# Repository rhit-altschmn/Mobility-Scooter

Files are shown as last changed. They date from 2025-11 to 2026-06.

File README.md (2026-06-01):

# Mobility-Scooter
This is a repo to handle code for automating a mobility scooter. A joint partnership between Intro to Robotics team and Dr. Bill Smart's lab. For this project, we added cameras and sensors to the scooter frame, designed a steering system to drive the scooter from afar, and hacked into the scooter's electrical system to power our new electronics. For more information about each of these systems please click the associated link. [Camera System](Cameras.md), [Sensors](Sensors.md), [Steering](SteeringSystem.md), [Electrical System](driveANDelectrical.md)  The scooter is teleoperated throuh a flask server hosted on the onboard Raspberry Pi. An external device can connect to the flask server by being on the same wifi network as the pi and entering the Pi IP address into the search bar. 

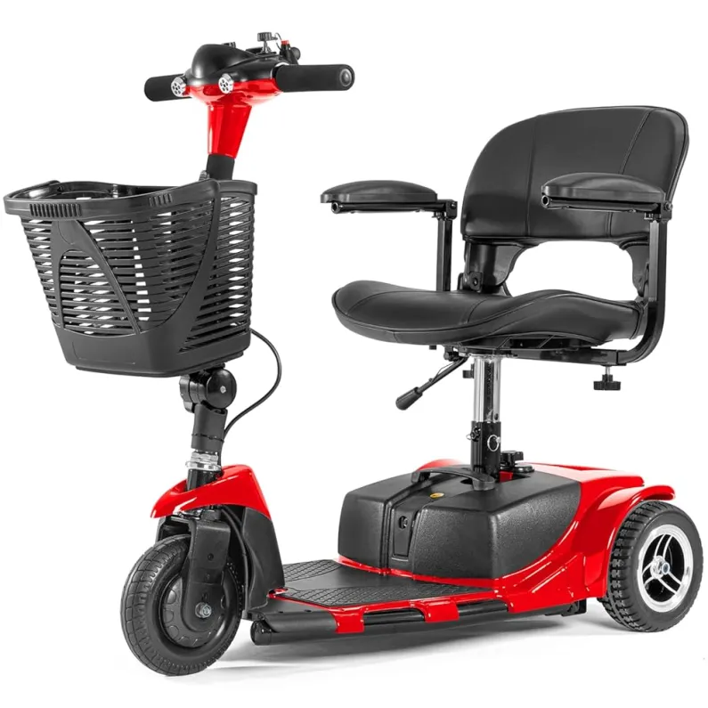
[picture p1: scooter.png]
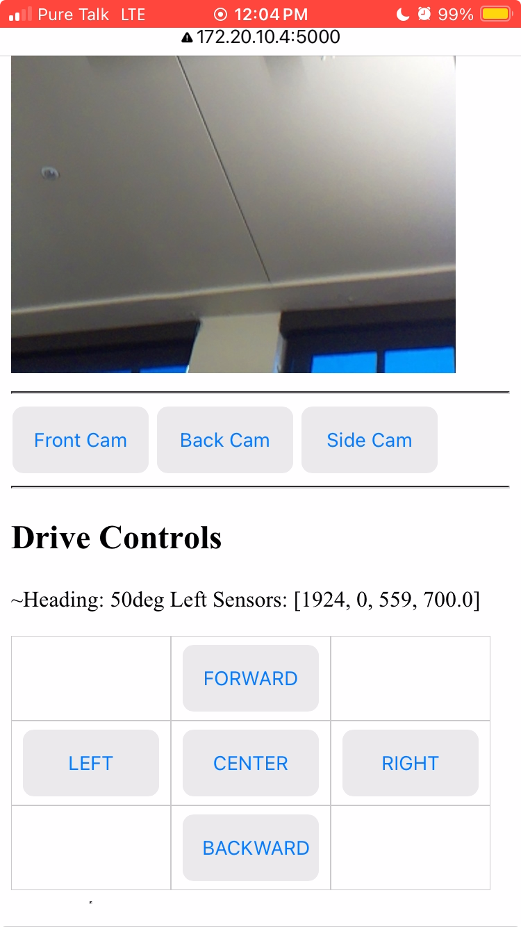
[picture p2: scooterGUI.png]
   &emsp; &emsp; &emsp; &emsp;     <br>
 &emsp; &emsp; &emsp; &emsp;  The Scooter   &emsp; &emsp; &emsp; &emsp; &emsp; &emsp; &emsp; &emsp;       Scooter Graphical User Interface 

<!--Quick guide to markdown (https://www.markdownguide.org/basic-syntax/#links)-->

## Hardware
* Raspberry Pi4 - the brain that runs code and hosts the flask server
* Stepper Motor - used with belt system on drive shaft for steering front wheel
* Voltage-stepdowns - used with PWM for controlling rear wheels powerin the scooter forward/backward
* Cameras (2 USB and 1 picam) - for viewing so users can teleop the scooter. maybe used for computer vision in future
* ultrasonics (4) - for object avoidance sensing

### Raspberry Pi info
Raspberry Pi login stuff:
username: scooterteam

password: scooter1

local LAN ssid: scooterwifi

password:scooter1

## Software
* scooterSite.py - runs the flask site html and handles camera frame creation and streaming to site
* templates/index.html - the html for the flask site
* static/main.js - the javascript to handle button pushes on the html
* scooterController.py - does all the backend scooter control:
  - initializes all the GPIO pins and serial ports
  - calls the appropriate functions for moving & turning scooter
  - handles ultrasonics gets readings and publishes them.
* motor_driver.py - calculates the correct pwm setting for desired turn angle

  all the other files are old testing files not needed in final scooter operation.

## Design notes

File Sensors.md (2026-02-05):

# Ultrasonic Distance Sensors

## Overview
Four [A02YYUW waterproof ultrasonic distances](https://www.dfrobot.com/product-1935.html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) were put on the scooter. One was placed to view each direction, with the left and right sensors being mounted low and pointed slightly upwards in an effort to see cars nearby in a parking lot scenario. The rear sensor uses a [3D printed mount](https://cad.onshape.com/documents/c4d6c58f98211453321110ab/w/8268dd0c223b57df2334ac4d/e/cfee72e95296e9f6bdb92858) inserted into the hitch. This file is also given as Ultrasonic and Camera Rear Mount in the Github. These distance readings are used for safe navigation, ensuring that a user or autonmous controller are aware of any obstacles.

## Setup
The A02YYUW operates at either 3.3 or 5V, and will output the same voltage. If using with a Raspberry Pi it is important to power with 3.3V to avoid damaging any pins. Please see the [datasheet](https://media.digikey.com/pdf/Data%20Sheets/DFRobot%20PDFs/SEN0311_Web.pdf) for relevant information.

Note that the blue wire is TX and Green is RX for UART.

Setup procedure on a new Pi is as follows:
1. Enable UART in config by using `sudo nano /boot/config.txt` and adding the following to the bottom:
   `dtoverlay=disable-bt  
   enable_uart=1  
   dtoverlay=uart3  
   dtoverlay=uart4  
   dtoverlay=uart5`  
2. Disable bluetooth with the following:
   `sudo systemctl disable hciuart.service  
   sudo systemctl mask hciuart.service  
   sudo reboot`  
3. Install pyserial with:
   `pip install pyserial`

## Code
Please see ultrasonic.py for example code on using the sensors. If the serial ports are not working you can verify the ports with `ls /dev/ttyAMA`. The CPU speed function is useful for checking the load cuased by the sensors, with speeds below 1100 being ideal for continouse use without cooling. For a Raspberry Pi 4B the wiring must be done as follows:
	Sensor 1: Blue(TX) to GPIO14, Green(RX) to GPIO15
	Sensor 2: TX to GPIO4, RX to GPIO5
	Sensor 3: TX to GPIO8, RX to GPIO9
	Sensor 4: TX to GPIO12, RX to GPIO13
The final intent for the sensors is to read distance and limit movement such that you cannot move closer to an object once a certain threshold is met. This is not yet implemented into the controls code.

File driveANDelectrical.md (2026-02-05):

## Drive System / Electrical Documentation

## Overview

The drives interface takes over from the user-operated paddle switch for vehicle control. In order to preserve user operation modes, the drive system switches it's command inputs between the human and the electronic interface.

## Electrical Infrastructure

The auxiliary electrical infrastructure of the vehicle is provided by a single voltage stepdown module. This module takes the 12V nominal bus of the scooter, tapped from the ignition/key circuit, and provides 5V power to the steering servomotor, Raspberry Pi, both drive DACs, and the drive relays.

Using a monitored/digital step-down in this role enabled amperage monitoring, and power draw estimations. In further exploration of this technology, this implementation or similar would be advised. Technically, at 5V, the steering motor is under-volted, but undervolting in this case was found to not have significant performance degradation.

## Drive Interface

The drive interface primarily consists of two ADCs, and two relays.

The relays, in their nominally closed position, allow passthrough or "connection" of the drive signal from the thumb-throttle potentiometer. When opened, the relays connect to driven outputs of the digital-to-analog converters, and send voltage outputs along those rails.

The potentiometer used by the driver is a wiper-style, with a single input, and two outputs. At zero command, both outputs are driven to about 2.5V. When given an input, one output is pulled high, and the other is driven low. In function, the DACs follow this same logic, one pulls higher, the other pulls lower. 

In addition, the motor controller has several safety features that make this problematic. Primarily, the controller monitors for voltage discontinuities, and input coherence. As such, changeover/switchover events from the manual control to the automatic control must occur at zero throttle command. To the controller, the 2.5V from the potentiometer must seamlessly become the 2.5V from the DACs, or a fault will trigger. This same rule applies in the reverse transition state, switching from automated to manual control requires the output to be zeroed. Additionally, the inputs to the controller are monitored in the time domain, so large instantaneous jumps in throttle from the DAC have the potential to trigger fault modes.

Fault modes (characterized by a generic 7-beep sequence) cannot be reset without a vehicle restart, and should be avoided at all costs. 

Proper sequencing of a drive input for movement is as follows:
1. User throttle at zero
2. DACs are spun-up to 2.5v or "zero" command, and a delay is recommended here
3. Relays are engaged, switching control to digital system
4. DACs are incrementally stepped up to drive command voltage (one goes up, other goes down)
5. Drive command voltage is sustained for the length of the movement
6. DACs are incrementally stepped down to zero
7. Relays are disenaged, returning control to user

Following this cycle will result in minimal fault engagements upon motion.

## Pitfalls / Known Issues

Common issues discovered with this implementation can be found below:

* Large throttle commands can trigger fault modes, typically above 25% forward throttle command. This is theorized to be a result of the usage of two individually-driven digital-to-analog converters. As commanded throttle increases, the noise floor between the two DAC outputs increases, suspected to trigger the fault condition in the controller. This is exascerbated by sustained operation of the throttle.
* Failure to increment/slowly build commanded throttle can trigger fault modes, due to discontinuity checks within the controller.
* The potentiometer is never fully removed from the circuit, and as such may have an unmodeled role in the fault triggering mechanics.
* Improper sequencing in control logic can trigger faults. Similarly, improper timing of input sequencing can have the same effect

## Current State / Reccomendations

Currently, the drive controller is capable of converting impulse (one off) movement inputs into incremental movements for short durations of time. This model was chosen over a sustained movement option for simplicity on the web-controller side. A sustained motion model is certainly more desireable, but as discussed above, the input system is sequence-dependent, and that was difficult to implement during the time allowed. The code to execute this can be found in scooterController.py

For future implementations, a twin-DAC solution should be moved away from, with instead the use of a 5V inverting op-amp providing direct inversion of one signal, without noise floor effects.

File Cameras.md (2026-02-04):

# Camera System Documentation

## Overview

During teleoperation of the mobility scooter, there is a high likelihood that the scooter may move out of the operator’s direct line of sight. To address this challenge, the team developed a three view camera system to provide continuous visual feedback of the scooter’s surroundings.

This system enables real time monitoring by providing views from the front, rear, and left side of the scooter. The left side view is particularly useful during docking operations. Together, these views improve situational awareness and enhance safe remote operation.

---

## Camera System

The camera system consists of one PiCamera and two USB cameras.

The PiCamera is mounted at the front of the scooter to provide the forward facing view.  
One USB camera is mounted at the rear to provide the back view.  
Another USB camera is mounted on the left side to assist during docking.

The PiCamera is connected directly to the Raspberry Pi 4B through the dedicated camera interface port. The two USB cameras are connected through USB extension cables to the available USB ports on the Raspberry Pi.

For demonstration purposes, non waterproof cameras were selected to reduce cost. However, these cameras can be enclosed in waterproof housings for outdoor or adverse weather use.

## Specifications
-  PiCamera            - https://www.raspberrypi.com/documentation/accessories/camera.html#camera-module-2
-  USB Camera(FIT0892) - https://www.digikey.com/en/products/detail/dfrobot/FIT0892/18069226

---

## Integration into the General System

The camera system is integrated into the local domain host using a Flask based web interface.

A single display window is designed to showcase the selected camera view. Three control buttons are provided to allow the operator to switch between camera feeds in real time:

- FRONT CAM for the front view  
- BACK CAM for the rear view  
- SIDE CAM for the left side view  

These controls enable flexible and efficient monitoring during teleoperation.

---

## Current State of the Camera System

Currently, the camera system is not fully operational due to power limitations of the Raspberry Pi when supporting all cameras and other system components simultaneously.

- The rear and side cameras are physically disconnected and unmounted from their designated positions  
- The PiCamera remains mounted but is currently disconnected  
- All other system components remain as described in the previous sections  

These limitations are temporary and will be addressed through future power management and hardware upgrades.

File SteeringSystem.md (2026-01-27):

## Steering System

### Overview
In order to drive automously we need to remotely steer the mobility system. The base mobility sccooter has no powered steering and is manually steered through turning the handle bars which turn a steering column. Therefore, the steering system needs to mount on the frame of the mobility scooter and allow powered steering.

### Goals
* Allow the pi to autonomously control the angle of the steering column when powered on
  * This assumes that there is no rider or additional weight on the scooter while being autonomously operated. 
* Allow the scooter rider to manually steer the scooter while riding it
  * This will require either  a clutch or backdriving the motor. For the sake of simplicity, we chose to backdrive the motor.
* Attach to the frame of the scooter with minimal damage or modifications
* Allow precise control of the angle of the front wheel.
  * For the sake of simplicity, this version is open loop control. 

### Design
The steering angle is controlled by driving a servo mounted the the frame and belted to the steering column. The 2:1 gear ratio combined with the manual leverage from the handle bars make it reasonable to backdrive the unpowered servo without much difficulty. The motor requires a stepdown in voltage from the system power and is connected to the voltage stepdown in the central control box. This resulted in the motor being slightly undervolted at 5V instead of 6V. During tests, the motor was slower, but no less accurate. The belt sprockets used are 3D printed based on McMaster-Carr sprockets. The largest sprocket is left unchanged. The smaller sprocket has a large hole bored through the middle to accomodate the steering column and a small hole perpendicular to that to accomodate the bolt on the steering column. To reduce skipping, it is important that the mount is as rigid as possible. There is a shim used in the clamp to help tension the belt appropriately. To control the servo, you can use the "motor_driver.py" file. This file contains a function that takes the desired angle and Hz as an input. Then, it can either return the needed duty cycle for the pwm, or it can directly set the pwm. The gear ratio can also be modified in the function. 

front

### Parts
* Annimos servo motor: https://www.amazon.com/dp/B0C69WWLWQ
* DROK DC Buck Converter: https://www.amazon.com/DROK-Converter-5-3V-32V-Regulator-Transformer/dp/B078Q1624B
* 1.75in OD Pulley: https://www.mcmaster.com/1277N23
* 3.28in OD Pulley: https://www.mcmaster.com/57105K32
* 13in Timing belt: https://www.mcmaster.com/1679K121
* 3D printed parts as shown in the CAD

### Installation
1. Print out both belt sprockets, both halves of the clamp, and the shim from the CAD.
2. Remove the two bolts on the steering column and split it into two pieces. Slide the smaller belt sproket and the belt on the steering column. Reattach the steering column.
3. Screw the round aluminum servo horn on to the large belt sprocket. Install sprocket on the servo.
4. Bolt the servo bracket to the clamp with a shim in between. The width of the shim can be adjusted to adjsut the tension in the belt. You may need to drill out the 3D printed holes. Screw the bracket into the servo motor. 
5. Align the clamp around the frame of the scooter. You may need to add a strip of double sided tape or foam to adjsut fit. Secure the belt around both sprockets. Bolt the two halves of the clamp together, starting with the bolt on the bottom.
6. Regularly inspect the mount for cracks or fatigue.
   
### Documentation
https://cad.onshape.com/documents?nodeId=2ab928cb0acfaec854c34554&resourceType=folder

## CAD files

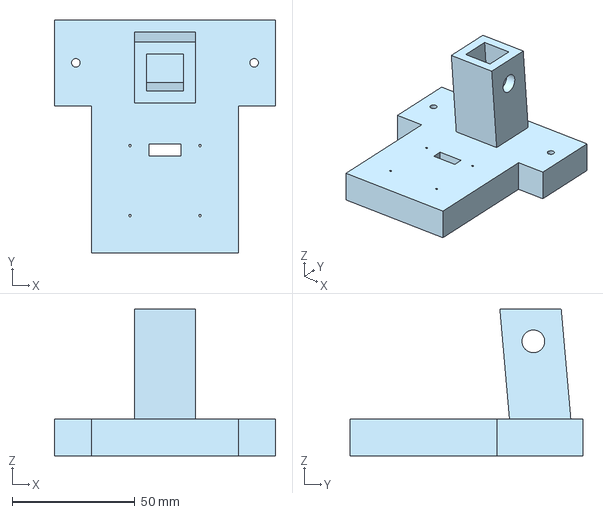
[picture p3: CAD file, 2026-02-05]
CADfiles/Ultrasonic and Camera Rear Mount.step
90.0 x 95.0 x 59.8 mm

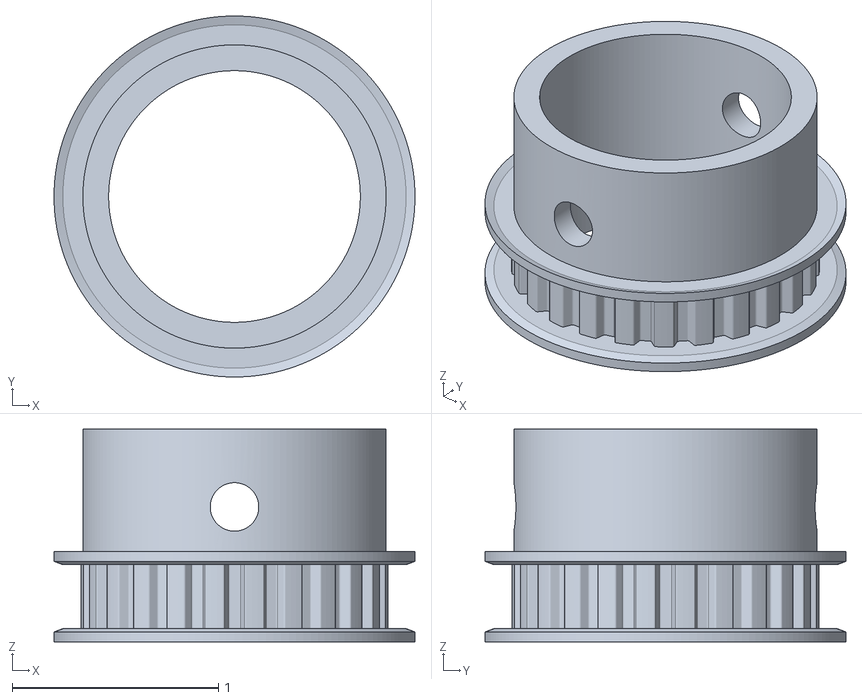
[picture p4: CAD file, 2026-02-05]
CADfiles/Small Belt Sprocket.stl
1.75 x 1.75 x 1.03

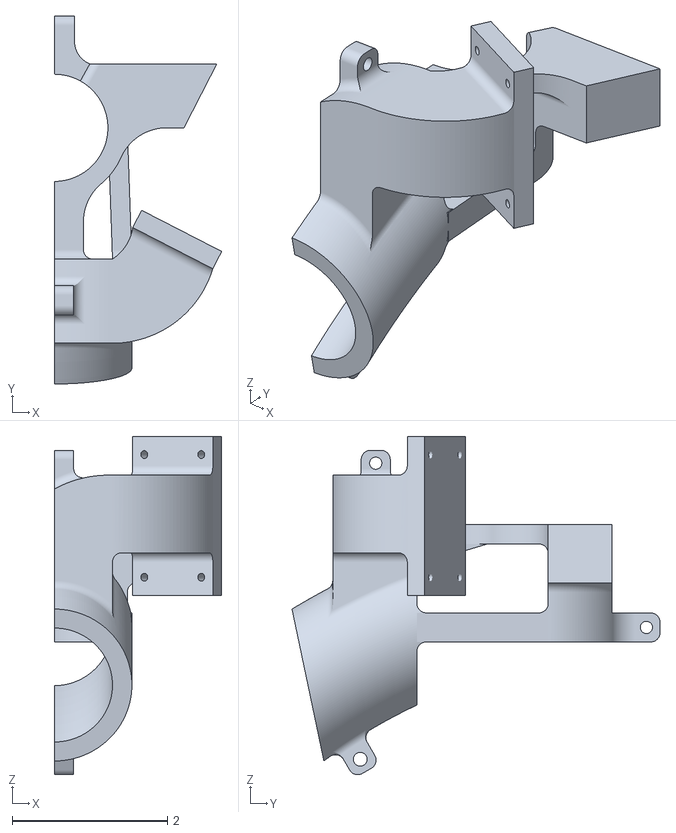
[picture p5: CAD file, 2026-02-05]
CADfiles/Actuator Clamp - Part 1.stl
2.16 x 4.74 x 4.36

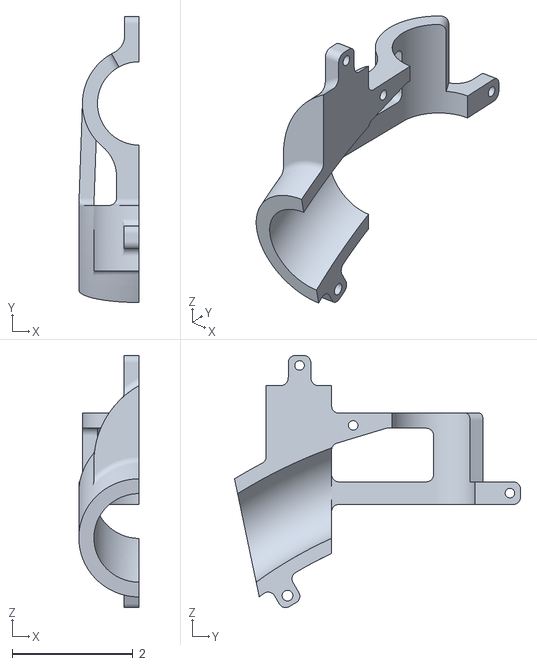
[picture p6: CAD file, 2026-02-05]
CADfiles/Actuator Clamp - Part 2.stl
1 x 4.74 x 4.18

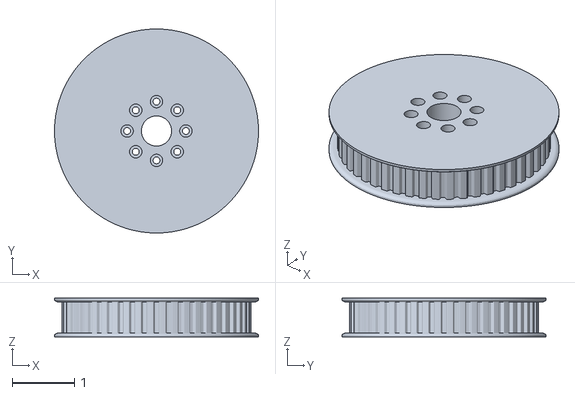
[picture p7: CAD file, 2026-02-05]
CADfiles/Large Belt Sprocket.stl
3.28 x 3.28 x 0.625

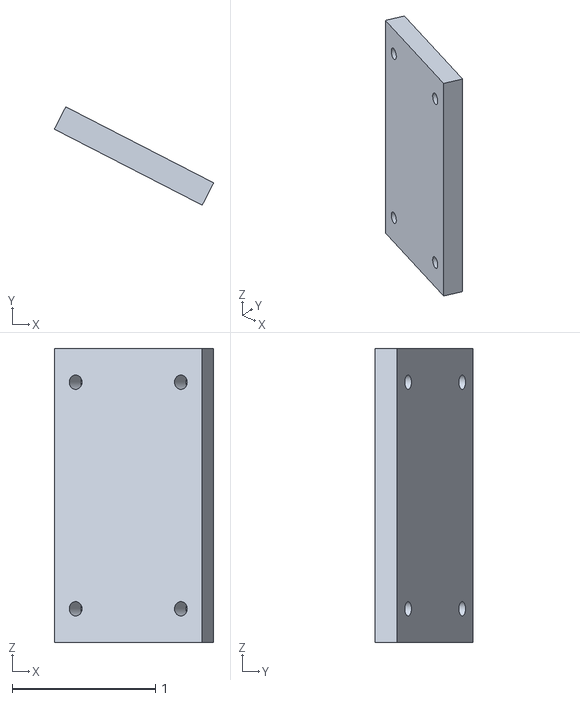
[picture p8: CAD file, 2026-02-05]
CADfiles/Actuator Clamp - Shim.stl
1.11 x 0.686 x 2.05

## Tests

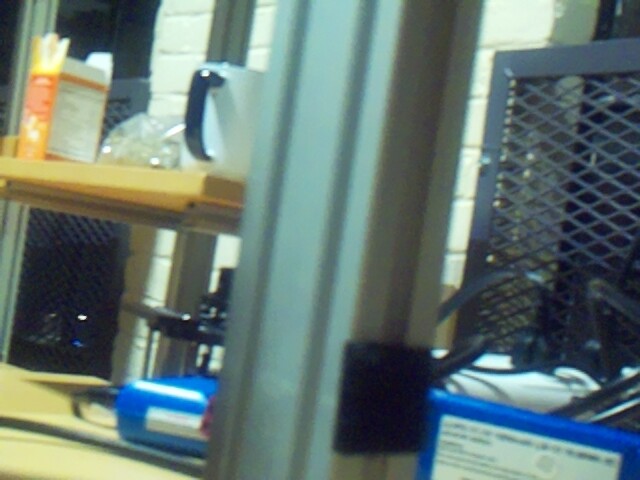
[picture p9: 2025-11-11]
testing_code/test.jpg

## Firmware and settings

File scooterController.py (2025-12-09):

import RPi.GPIO as GPIO
from time import sleep

import motor_driver
GPIO.setmode(GPIO.BOARD)

import serial
#import ultrasonic just copied functions
import random


class scooterController:

    def __init__(self):
        #pwm.stop()
        GPIO.setup(40,GPIO.OUT) # DAC1 pwm
        GPIO.setup(38,GPIO.OUT) # relay 1 hi/lo
        GPIO.setup(37,GPIO.OUT) # DAC2 pwm
        GPIO.setup(35,GPIO.OUT) # relay 2 hi/lo
        GPIO.setup(11,GPIO.OUT) #change this pin as needed
        
        self.Hz = 250
        
               
        self.pwm = GPIO.PWM(11,self.Hz) #MOTOR HZ CAN BE 50-330
        self.pwm1 = GPIO.PWM(40,1000) #set duty cycle to 50Hz or 20 ms
        self.pwm2 = GPIO.PWM(37,1000) #set duty cycle to 50Hz or 20 ms
        #operating frequency is 50-330Hz

        #motor operates from 500-2500 microseconds or 0.5-2.5ms
        #motor nuetral is at 1500 microseconds or 1.5ms

        #set motor to neutral
        self.heading = 0
        cycle = motor_driver.turn_to_angle(self.heading,self.Hz)
        self.pwm.start(cycle) #sets to center
        
        sleep(1)
        print("resetting header")

        # Assigned Pins:
        # S1: Blue(TX) to GPIO14, Green(RX) to GPIO15
        # S2: TX to GPIO4, RX to GPIO5
        # S3: TX to GPIO8, RX to GPIO9
        # S4: TX to GPIO12, RX to GPIO13
        # Setting serial ports for each sensors, skip AMA1 and 2
        self.ports=[
                serial.Serial("/dev/ttyAMA0",9600,timeout=0.1),
                #serial.Serial("/dev/ttyAMA3",9600,timeout=0.1),
                serial.Serial("/dev/ttyAMA4",9600,timeout=0.1),
                serial.Serial("/dev/ttyAMA5",9600,timeout=0.1)
        ]
        # Flushing ports and waiting for sensors to stabilize
        print("Resetting serial ports")
        for ser in self.ports:
            ser.reset_input_buffer()
        sleep(1.0)

        self.distances = []
        
    def read_dist(self,ser):
        data=ser.read(4)
        distance = (data[1] * 256 + data[2])
        #print(f"single dist read: {distance}")
        return distance
        
    def distance_read(self):
        self.distances = []        
        for ser in self.ports: # Add each distance reading
                ser.reset_input_buffer()
                dist = self.read_dist(ser)
                #if self.distances != None:
                self.distances.append(dist)
        with open("/sys/devices/system/cpu/cpu0/cpufreq/scaling_cur_freq") as cpu:
                Speed = int(cpu.read().strip()) / 1000 # Convert to mHz
                self.distances.append(Speed)
        #print(f"dist read: {self.distances}")

    def controlCommand(self,command):
        print(f"Controller Read: {command}")
        
        self.distance_read()
        print(f"Controller Distances: {self.distances}")
        #self.distances.append(random.randint(0,9)) # For sensor 4, not attached yet
        
        match command:

            case "RIGHT":
                self.heading = self.heading -10
                if self.heading < -70:
                    self.heading = -70
                cycle = motor_driver.turn_to_angle(self.heading,self.Hz)
                self.pwm.ChangeDutyCycle(cycle)
                print(f"Right: {self.heading}  {cycle}")
                
            case "CENTER":
                self.heading = self.heading * 0.75
                cycle = motor_driver.turn_to_angle(self.heading,self.Hz)
                self.pwm.ChangeDutyCycle(cycle)
                sleep(0.2)
                self.heading = self.heading * 0.5
                cycle = motor_driver.turn_to_angle(self.heading,self.Hz)
                self.pwm.ChangeDutyCycle(cycle)
                sleep(0.2)
                self.heading = self.heading * 0.5
                cycle = motor_driver.turn_to_angle(self.heading,self.Hz)
                self.pwm.ChangeDutyCycle(cycle)
                sleep(0.2)
                self.heading = 0
                cycle = motor_driver.turn_to_angle(self.heading,self.Hz)
                self.pwm.ChangeDutyCycle(cycle)
                print(f"Center: {self.heading}  {cycle}")
                
            case "LEFT":
                self.heading = self.heading + 10
                if self.heading > 70:
                    self.heading = 70
                cycle = motor_driver.turn_to_angle(self.heading,self.Hz)
                self.pwm.ChangeDutyCycle(cycle)
                print(f"Left: {self.heading}  {cycle}")
            case "FORWARD":
                # call the actual gas pedal thing here
                print(f"Calling Drive Forward. Heading: {self.heading}")
                self.pwm1.start(50+20) #sets pwm to 7.5% of duty cycle, or 1.5ms
                self.pwm2.start(50-20) #sets pwm to 7.5% of duty cycle, or 1.5ms
                sleep(0.25)

                GPIO.output(38, 0)
                GPIO.output(35, 0)
                sleep(1)

                self.pwm1.ChangeDutyCycle(50)
                self.pwm2.ChangeDutyCycle(50)
                sleep(0.1)
                GPIO.output(38, 1)
                GPIO.output(35, 1)
                sleep(.1)
                
                
            case "REVERSE":
                # call the actual gas pedal thing here
                print(f"Calling Drive Reverse. Heading: {self.heading}")
                self.pwm1.start(50-10) #sets pwm to 7.5% of duty cycle, or 1.5ms
                self.pwm2.start(50+10) #sets pwm to 7.5% of duty cycle, or 1.5ms
                sleep(.25)

                GPIO.output(38, 0)
                GPIO.output(35, 0)
                sleep(1.75)

                self.pwm1.ChangeDutyCycle(50)
                self.pwm2.ChangeDutyCycle(50)
                #sleep(0.1)
                GPIO.output(38, 1)
                GPIO.output(35, 1)
                sleep(0.25)
                
            case "STOP":
                # stop the drive pwms
                print(f"Stopping!!!")
                self.pwm1.ChangeDutyCycle(50)
                self.pwm2.ChangeDutyCycle(50)
                sleep(0.1)
                GPIO.output(38, 1)
                GPIO.output(35, 1)
                sleep(0.1)
                # pwm.stop()
                # GPIO.cleanup()

        return command,self.heading,self.distances


if __name__ == "__main__":

    cont = scooterController()
    while True:
        resp = ""
        
        selection = input("Make a selection: ")
        if selection == "EXIT":
            break
        else:
            resp = cont.controlCommand(selection)
            print(resp)
        
    cont.pwm.stop()
    # cont.GPIO.cleanup() 
    print("Goodbye")
        

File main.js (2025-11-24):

function main(){    

    document.querySelector("#FC").onclick = () => {
        sendCommand("FRONT CAM");
    };
    document.querySelector("#BC").onclick = () => {
        sendCommand("BACK CAM");
    };
    document.querySelector("#SC").onclick = () => {
        sendCommand("SIDE CAM");
    };
    
    document.querySelector("#F").onclick = () => {
        sendCommand("FORWARD");
    };
    document.querySelector("#B").onclick = () => {
        sendCommand("BACKWARD");
    };
    document.querySelector("#L").onclick = () => {
        sendCommand("LEFT");
    };
    document.querySelector("#C").onclick = () => {
        sendCommand("CENTER");
    };
    document.querySelector("#R").onclick = () => {
        sendCommand("RIGHT");
    };
   
}

async function sendCommand(command){
    let response = await fetch(`/api/${command}`);
    let responseText = await response.text();
    console.log(responseText);
    const respArray = responseText.split("?")
    //TODO: Actually show the user on screen
    document.querySelector("#responseText").innerHTML = responseText;
    
    const infoText = "Heading: " + respArray[1] + "  Sensors: " + respArray[2]
    document.querySelector("#scooterInfo").innerHTML = infoText;
}

main();

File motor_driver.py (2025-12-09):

def turn_to_angle(angle,hz): #, pwm
    """This assumes that the motor is in pin 11 and 50 Hz. Takes values between -67.5 and 67.5 for angles"""
    #Mechanical parameters
    print(f"Input Angle: {angle}")
    
    gear_ratio = 2
    #Hz = 250
    cycle_length = ((1/hz) * 1000) #in ms

    #Motor parameters
    operating_range = 2000 #microseconds
    min_width = 500 #microseconds
    operating_angle = 270

    turn_angle = (angle / gear_ratio) + operating_angle/2 #returns a value beetween 0 and 270

    width = ((operating_range/operating_angle * turn_angle) + min_width) / 1000 #calculates the pulse width in ms assuming linear relationship

    duty_cycle = width / cycle_length * 100 #finds what percent of the duty_cycle corresponds to that pulse width

    # pwm.ChangeDutyCycle(duty_cycle)
    return duty_cycle

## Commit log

2025-11-04 change button size
2025-11-19 Added distance function to ultrasonic
2025-11-25 new socketio test
2025-11-26 edit ultrasonic
2025-12-02 drive test/drive driver code
    first commit - drive_driver is nonexistent dont use
2025-12-02 altered drive test
    now uses two relays
2025-12-02 steering integration &relay test
2025-12-03 update heading print
2025-12-03 update heading printout
2025-12-03 old driver test code
    uploaded
2025-12-03 fixed file name
    file name
    [driver_test_v2old.py]
2025-12-04 fix forward & reverse
    [scooterController.py]
2025-12-05 modify center move stop skipping
    [scooterController.py]
2025-12-08 multicam on buttons
2025-12-09 button holding?
2025-12-09 current demo code
2026-01-27 Update and rename CustomHardware.md to Steering System.md
2026-01-27 Update Steering System.md
2026-06-01 Rename Steering System.md to SteeringSystem.md
